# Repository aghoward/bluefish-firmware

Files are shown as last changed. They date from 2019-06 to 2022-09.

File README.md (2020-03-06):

# bluefish password manager

bluefish is a hardware based password manager made to be easily transportable, cheap,
and secure.

## What's in this repository?

This repository contains the firmware and KiCad / Gerber files necessary for the hardware
to work. The hardware is based on the Arduino platform and requires some libraries from
the official Arduino standard library. You'll also need a few supporting libraries from
my own collection: [STL](https://github.com/aghoward/stl) and 
[either](https://github.com/aghoward/either). These will both need to be installed along
side other arduino libraries for the compiler to find them.

A make file has been provided which should allow you to compile the code for your atmel
chip; out of the box you can specify one of the following: `UNO=true`, `LEONARDO=true`,
`NANO=true`, or `MIGHTY1284P` to build for a specific platform. The most tested of these
is the UNO platform which is a atmel ATMega328P.

You can use `make` to build the code; and `make up` to use avrdude to flash the firmware
to your atmel chip. Have a look inside the hardware folder to find the wiring schematics
and all files necessary to print your own PCBs.

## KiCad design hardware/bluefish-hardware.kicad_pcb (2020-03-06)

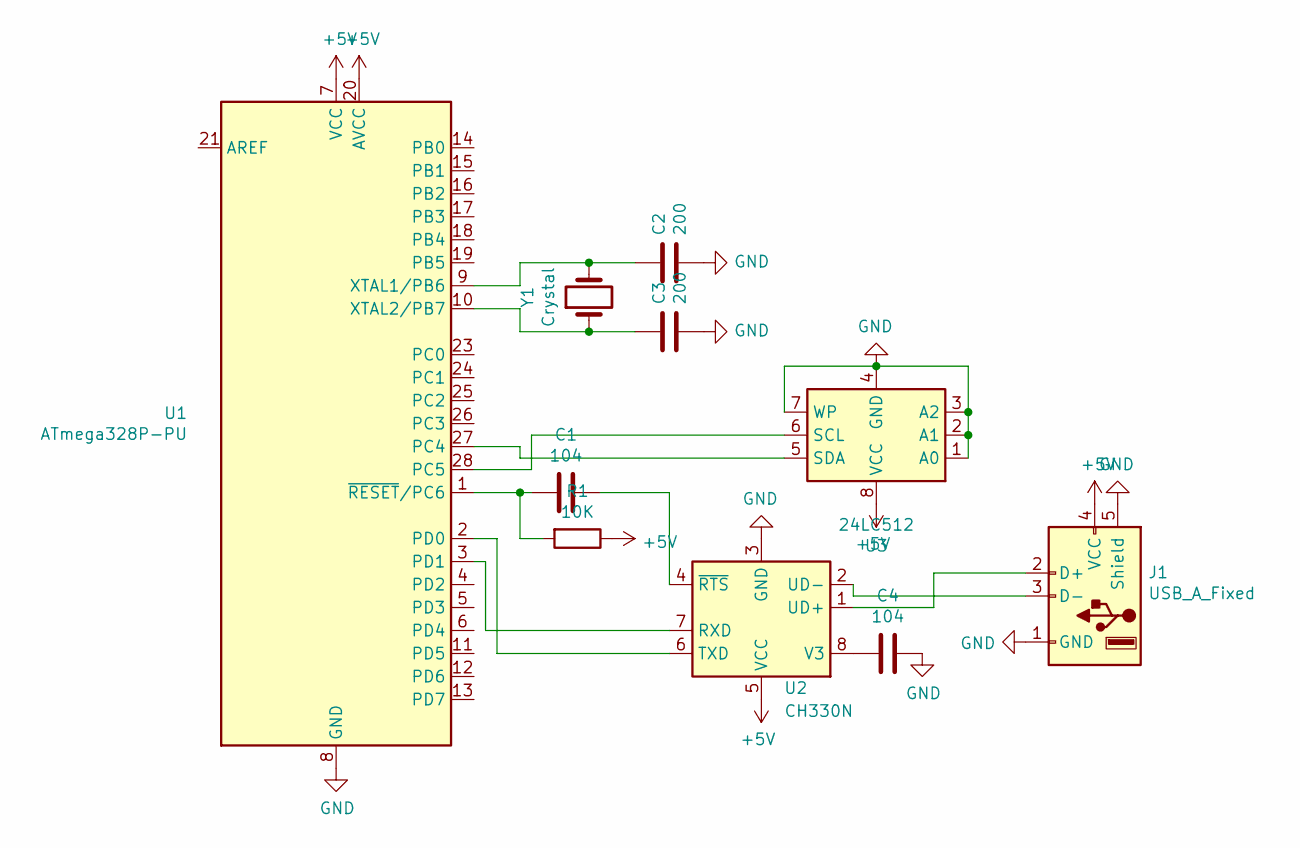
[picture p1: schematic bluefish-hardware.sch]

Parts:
C1, C4: 104; C_Rect_L7.0mm_W3.5mm_P5.00mm
C2, C3: 200; C_Rect_L7.0mm_W3.5mm_P5.00mm
J1: USB_A_Fixed; USB_A_Stewart_SS-52100-001_Horizontal
R1: 10K; R_Axial_DIN0207_L6.3mm_D2.5mm_P7.62mm_Horizontal
U1: ATmega328P-PU; DIP-28_W7.62mm
U2: CH330N; SOIC-8_3.9x4.9mm_P1.27mm
U3: 24LC512; DIP-8_W7.62mm_Socket
Y1: Crystal; Crystal_HC49-4H_Vertical

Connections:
+5V: J1.4 (VCC), R1.1, U1.7 (VCC), U1.20 (AVCC), U2.5 (VCC), U3.8 (VCC)
GND: C2.2, C3.2, C4.2, J1.1 (GND), J1.5 (Shield), U1.8 (GND), U1.22 (GND), U2.3 (GND), U3.1 (A0), U3.2 (A1), U3.3 (A2), U3.4 (GND), U3.7 (WP)
unnamed: C1.1, R1.2, U1.1 (~RESET~/PC6)
unnamed: C1.2, U2.4 (~RTS)
unnamed: C2.1, U1.9 (XTAL1/PB6), Y1.2
unnamed: C3.1, U1.10 (XTAL2/PB7), Y1.1
unnamed: C4.1, U2.8 (V3)
unnamed: J1.2 (D+), U2.1 (UD+)
unnamed: J1.3 (D-), U2.2 (UD-)
unnamed: U1.2 (PD0), U2.6 (TXD)
unnamed: U1.3 (PD1), U2.7 (RXD)
unnamed: U1.27 (PC4), U3.5 (SDA)
unnamed: U1.28 (PC5), U3.6 (SCL)

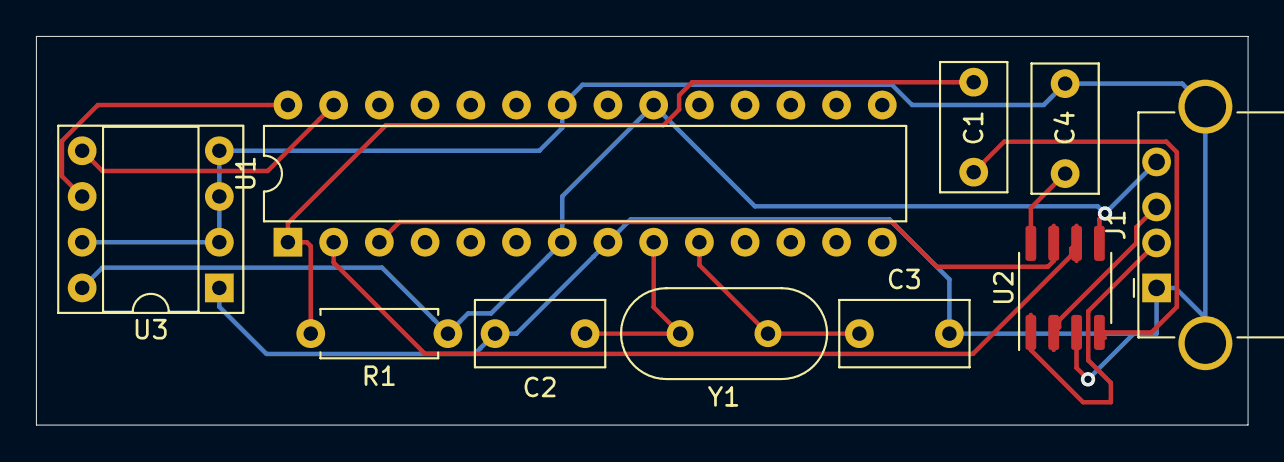
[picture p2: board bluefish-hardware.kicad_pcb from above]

Board: 2 copper layers, 67.3 x 21.6 mm, 10 parts (0 on the bottom side), 13 nets.

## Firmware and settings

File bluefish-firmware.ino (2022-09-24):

#include <Arduino.h>
#include <Wire.h>
#include <memory.h>

#include "file_system.h"
#include "file.h"
#include "char_string.h"

#include "api.h"
#include "binary_api.h"

std::unique_ptr<API> _api;

void setup()
{
    pinMode(2, OUTPUT);
    pinMode(3, OUTPUT);
    Wire.begin();
    Wire.setClock(400000);

    digitalWrite(2, HIGH);
    Serial.begin(115200);
    while (!Serial) {}

    _api = std::make_unique<BinaryAPI>();
    digitalWrite(2, LOW);
}

void loop()
{
    auto command = _api->read_command();
    _api->process_command(command);
}

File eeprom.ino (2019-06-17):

#include <Arduino.h>
#include <Wire.h>
#include <memory.h>

#include "file_system.h"
#include "file.h"
#include "char_string.h"

#include "api.h"
#include "text_api.h"

std::unique_ptr<API> _api;

void setup()
{
    Wire.begin();

    Serial.begin(115200);
    while (!Serial) {}
    Serial.println("Begin...");

    _api = std::make_unique<TextAPI>();
    Serial.println("Filesystem initialized!");
}

void loop()
{
    while (!Serial.available()) {}

    auto command = _api->read_command();
    _api->process_command(command);
}

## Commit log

2019-04-13 Initial Attempt
    Adds the basics for reading / writing the EEPROM (24LC16B) as a
    continous block of memory.
    Adds a simple filesystem that works for name, username, password
    combinations. Can read and list files by name.
    Adds STL like vector, probably not good enough to include in the STL
    implementation
2019-06-17 Implement API objects
    Moves the majority of the logic out of the `eeprom.ino` file and into an
    API object. Retains the old communication mechanism as a `TextAPI` and
    implements a new API as a binary protocol.
    Additionally, fixed an SRP violation in `FileSystem` where it was
    directly communicating with the serial interface to provide usage
    statistics
    [eeprom.ino]
2019-11-07 Give project a proper name
    Project has been renamed, for too long this was simply called
    "eeprom-filesystem" it is much more than that now. It has been renamed
    "bluefish" with this hardware based component getting the name
    "bluefish-firmware". Bluefish is inspired by the name of the encryption
    algorithm to be used on the client side, "Twofish", and a play on Dr.
    Seuss' story "One fish two fish red fish blue fish".
    [bluefish-firmware.ino]
2019-11-07 Upgrade Filesystem
    Updates filesystem to allow bigger storage devices
2019-11-07 Store Encryption IV in Master Block
    The format call now requires an encryption IV to be stored in the master
    block. This allows creating unique IV's per format.
    Required making `CharString` copyable, though this should still be used
    sparingly.
    Renames `print_usage` to `get_master_block` to better describe what's
    actually happening
2019-11-12 Implement Larger EEPROM
    Implements a driver for a larger EEPROM, the 24lc512, while still
    allowing the older 24lc16b to be used.
2019-11-15 Update API to Use IDs instead of strings
    Previously strings were being used for unique identification, but this
    is problematic for MCUs with smaller amounts of RAM, and also stringly
    typed things are bad.
    [bluefish-firmware.ino]
2019-11-17 Fix EEPROM Bug
    Fixes issue in the 24lc512 EEPROM which caused invalid accesses if
    trying to write past the first page
    [24lc512.cpp]
2020-01-29 Simplify Binary API Read For Callers
    Previously a caller was expected to get a list of all file ids and read
    each one's filename individually to see if matched the filename they
    were looking for. This has been improved to only ask the caller to
    encrypt the filename first, send it to the device and the device will
    return the appropriate file after finding it by name.
2020-03-06 Add First Hardware Revision
    Adds all kicad and gerber files for the first revision of DIP and
    through-hole boards.
    [bluefish-hardware-B_Cu.gbl, bluefish-hardware-B_Mask.gbs, bluefish-hardware-B_Paste.gbp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]
2022-09-24 Update Either API
    Switches to updated either library which had an API change.
2022-09-24 Increase I2C Bus Speed
    The EEPROM supports a max speed of 400KHZ. Now that the memory issues
    are resolved the device can comfortably run at that speed.
    [bluefish-firmware.ino]
